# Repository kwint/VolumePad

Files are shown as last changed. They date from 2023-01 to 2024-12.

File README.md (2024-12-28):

# VolumePad

Proof of concept of a numpad / macropad with motorized faders to control volume. Fader position is also updated if you change the volume on the pc.

The main problem it tries to solve is noisy friends in discord while you are trying to clutch a csgo match

Current state of the project; PCB needs a lot of work, the original motor driver uses to much power and the fingerprint of the faders is wrong. The microcontoller code fully works, it uses MIDI for communication with the host. On windows you can use [MIDI Mixer](https://www.midi-mixer.com/). Haven't found a similar solution yet on linux, but shouldn't be hard to make. (The code in `code/host` is from before I moved the project over to MIDI).

https://user-images.githubusercontent.com/7907280/210675597-fe70f985-09b6-4afa-9840-3089a5ae9c90.mp4

## TODO:
### Code:
 - Create code for host machine
 - The capacitive button check needs work, might be electrical related
 - Clean up

### Electrical
 - Use newer motor driver
 - Fix footprint of faders
 - I think something is wrong with the capacitive button wiring

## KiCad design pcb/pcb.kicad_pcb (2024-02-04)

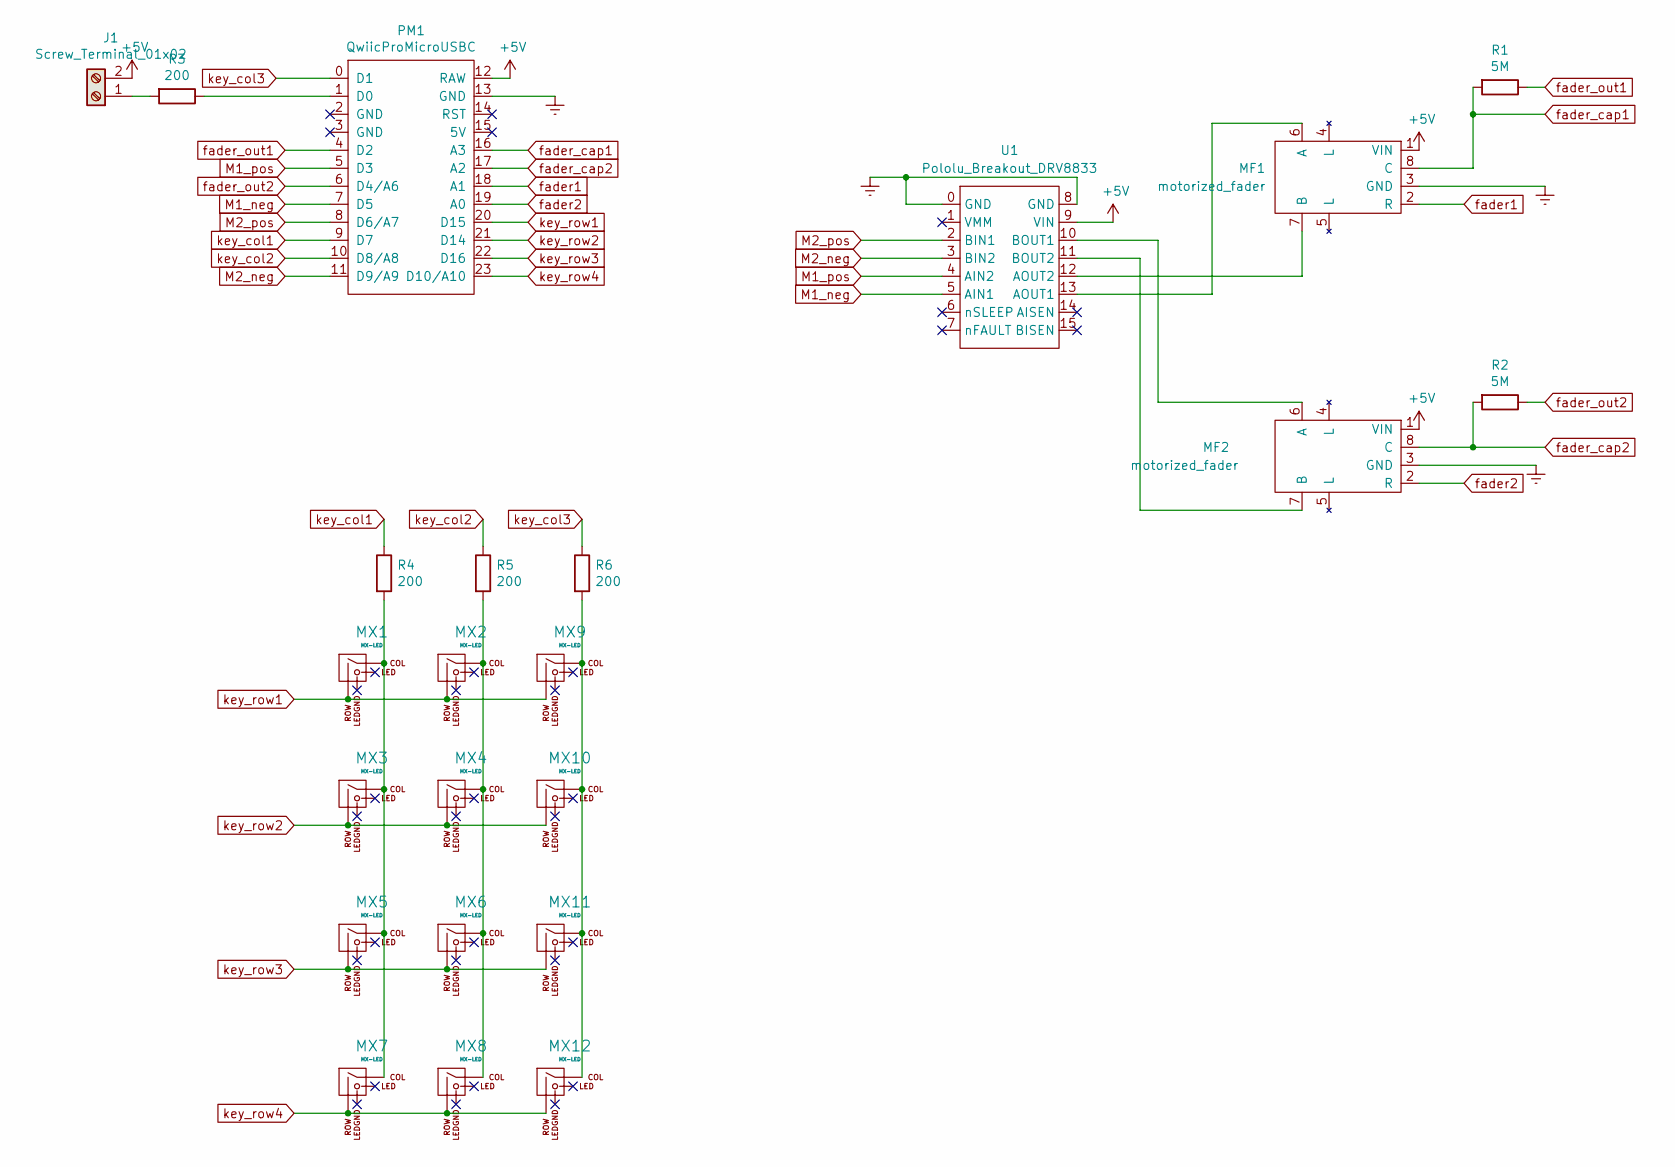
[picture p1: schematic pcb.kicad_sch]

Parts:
J1: Screw_Terminal_01x02; TerminalBlock_bornier-2_P5.08mm
MF1, MF2: motorized_fader
MX1, MX2, MX3, MX4, MX5, MX6, MX7, MX8, MX9, MX10, MX11, MX12: MX-LED; SW_Cherry_MX_1.00u_PCB
PM1: QwiicProMicroUSBC
R1, R2: 5M; R_Axial_DIN0207_L6.3mm_D2.5mm_P10.16mm_Horizontal
R3, R4, R5, R6: 200; R_Axial_DIN0207_L6.3mm_D2.5mm_P10.16mm_Horizontal
U1: Pololu_Breakout_DRV8833; Pololu_DRV8833

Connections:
+5V: J1.2, MF1.1 (VIN), MF2.1 (VIN), PM1.12 (RAW), U1.9 (VIN)
Earth: MF1.3 (GND), MF2.3 (GND), PM1.13 (GND), U1.0 (GND), U1.8 (GND)
M1_neg: PM1.7 (D5), U1.5 (AIN1)
M1_pos: PM1.5 (D3), U1.4 (AIN2)
M2_neg: PM1.11 (D9/A9), U1.3 (BIN2)
M2_pos: PM1.8 (D6/A7), U1.2 (BIN1)
unnamed: J1.1, R3.2
unnamed: MF1.6 (A), U1.13 (AOUT1)
unnamed: MF1.7 (B), U1.12 (AOUT2)
unnamed: MF2.6 (A), U1.10 (BOUT1)
unnamed: MF2.7 (B), U1.11 (BOUT2)
unnamed: MX1.1 (COL), MX3.1 (COL), MX5.1 (COL), MX7.1 (COL), R4.2
unnamed: MX2.1 (COL), MX4.1 (COL), MX6.1 (COL), MX8.1 (COL), R5.2
unnamed: MX9.1 (COL), MX10.1 (COL), MX11.1 (COL), MX12.1 (COL), R6.2
unnamed: PM1.1 (D0), R3.1
fader1: MF1.2 (R), PM1.18 (A1)
fader2: MF2.2 (R), PM1.19 (A0)
fader_cap1: MF1.8 (C), PM1.16 (A3), R1.2
fader_cap2: MF2.8 (C), PM1.17 (A2), R2.2
fader_out1: PM1.4 (D2), R1.1
fader_out2: PM1.6 (D4/A6), R2.1
key_col1: PM1.9 (D7), R4.1
key_col2: PM1.10 (D8/A8), R5.1
key_col3: PM1.0 (D1), R6.1
key_row1: MX1.2 (ROW), MX2.2 (ROW), MX9.2 (ROW), PM1.20 (D15)
key_row2: MX3.2 (ROW), MX4.2 (ROW), MX10.2 (ROW), PM1.21 (D14)
key_row3: MX5.2 (ROW), MX6.2 (ROW), MX11.2 (ROW), PM1.22 (D16)
key_row4: MX7.2 (ROW), MX8.2 (ROW), MX12.2 (ROW), PM1.23 (D10/A10)

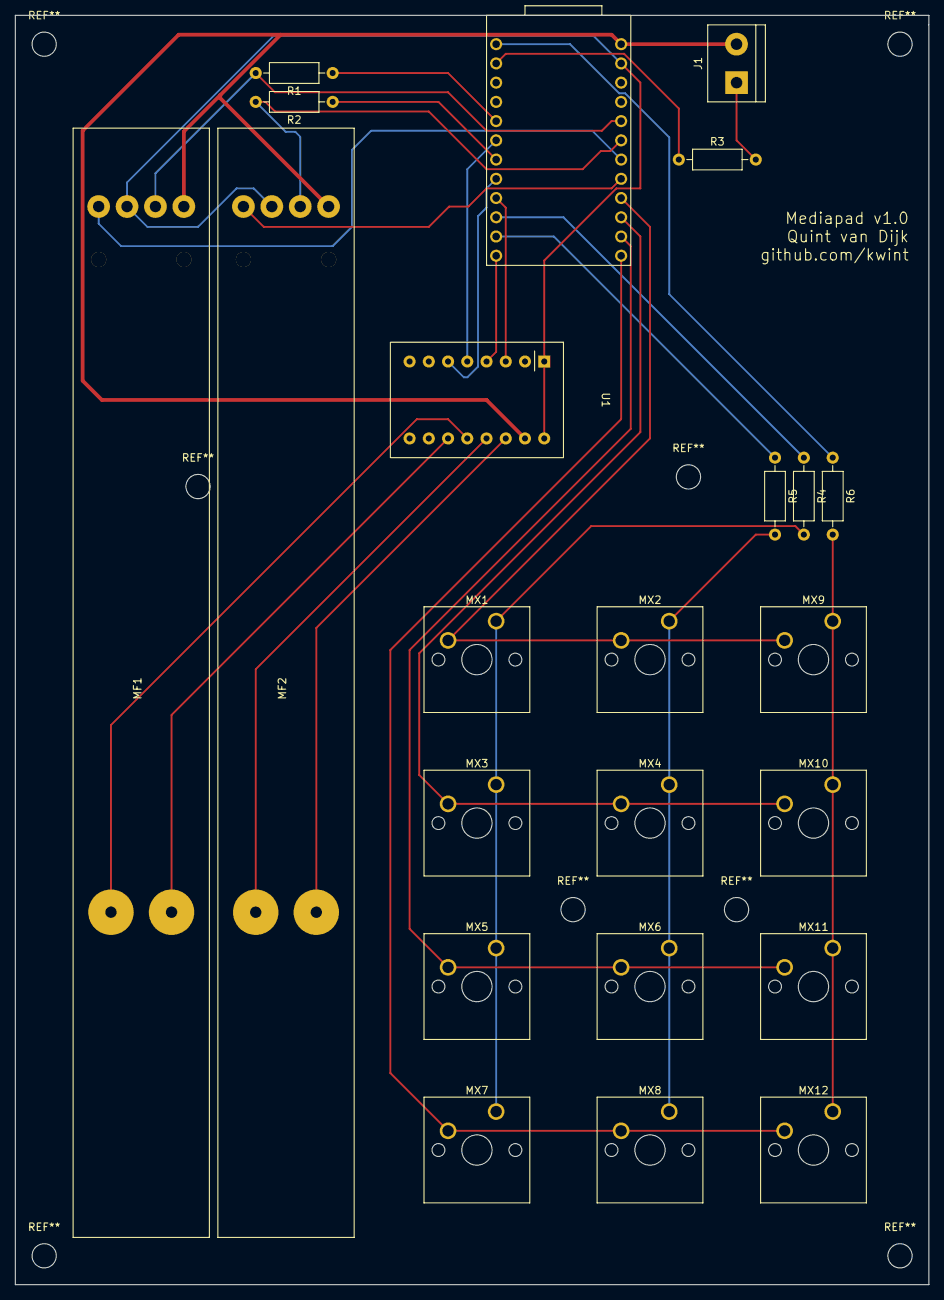
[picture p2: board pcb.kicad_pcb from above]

Board: 2 copper layers, 120.6 x 167.6 mm, 23 parts (0 on the bottom side), 28 nets.

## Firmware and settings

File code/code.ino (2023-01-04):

#include <Arduino.h>
#include "Adafruit_Keypad.h"
#include "order.h"
#include "slave.h"
#include "parameters.h"

bool isConnected = false; ///< True if the connection with the master is available

int RXLED = 17; // The RX LED has a defined Arduino pin
// Note: The TX LED was not so lucky, we'll need to use pre-defined
// macros (TXLED1, TXLED0) to control that.
// (We could use the same macros for the RX LED too -- RXLED1,
//  and RXLED0.)

int16_t fader0Pos = 0;
int16_t fader1Pos = 0;

int16_t oldFader0Pos = 0;
int16_t oldFader1Pos = 0;

bool fader0Updating = false;
bool fader1Updating = false;

unsigned long lastDebug;

Adafruit_Keypad numpad = Adafruit_Keypad(makeKeymap(keys), rowPins, colPins, ROWS, COLS);

void setup()
{
  // Init Serial
  Serial.begin(SERIAL_BAUD);

  pinMode(fader0Up, OUTPUT);
  digitalWrite(fader0Up, LOW);
  pinMode(fader0Down, OUTPUT);
  digitalWrite(fader0Down, LOW);

  pinMode(fader1Up, OUTPUT);
  digitalWrite(fader1Up, LOW);
  pinMode(fader1Down, OUTPUT);
  digitalWrite(fader1Down, LOW);

  // Wait until the arduino is isConnected to master
  while (!isConnected)
  {
    writeOrder(HELLO);
    waitForBytes(1, 1000);
    getMessageFromSerial();
  }
}

void loop()
{
  getMessageFromSerial();
  setFaders();

  sendFaders();
}

void sendFaders()
{
  int16_t fader0CurrentPos;
  int16_t fader1CurrentPos;

  fader0CurrentPos = analogRead(fader0Read);
  fader1CurrentPos = analogRead(fader1Read);

  if (!fader0Updating && (fader0CurrentPos < (oldFader0Pos - faderHysteresis) || fader0CurrentPos > (oldFader0Pos + faderHysteresis)))
  {
    writeOrder(FADER0);
    writeI16(fader0CurrentPos);
    writeI16(32767);
    oldFader0Pos = fader0CurrentPos;
  }
  if (!fader1Updating && (fader1CurrentPos < (oldFader1Pos - faderHysteresis) || fader1CurrentPos > (oldFader1Pos + faderHysteresis)))
  {
    writeOrder(FADER1);
    writeI16(fader1CurrentPos);
    writeI16(32767);
    oldFader1Pos = fader1CurrentPos;
  }
}

void setFaders()
{
  int16_t fader0CurrentPos;
  int16_t fader1CurrentPos;

  if (fader0Updating)
  {
    fader0CurrentPos = analogRead(fader0Read);
    oldFader0Pos = fader0CurrentPos;
    if (fader0CurrentPos > (fader0Pos - faderHysteresis) && fader0CurrentPos < (fader0Pos + faderHysteresis))
    {
      fader0Updating = false;
      digitalWrite(fader0Down, LOW);
      digitalWrite(fader0Up, LOW);
    }
    else if (fader0Pos < fader0CurrentPos)
    {
      digitalWrite(fader0Up, LOW);
      analogWrite(fader0Down, motorSpeed);
    }
    else if (fader0Pos > fader0CurrentPos)
    {
      digitalWrite(fader0Down, LOW);
      analogWrite(fader0Up, motorSpeed);
    }
  }

  if (fader1Updating)
  {
    fader1CurrentPos = analogRead(fader1Read);
    oldFader1Pos = fader1CurrentPos;
    if (fader1CurrentPos > (fader1Pos - faderHysteresis) && analogRead(fader1Read) < (fader1Pos + faderHysteresis))
    {
      fader1Updating = false;
      digitalWrite(fader1Down, LOW);
      digitalWrite(fader1Up, LOW);
    }
    else if (fader1Pos < fader1CurrentPos)
    {
      digitalWrite(fader1Up, LOW);
      analogWrite(fader1Down, motorSpeed);
    }
    else if (fader1Pos > fader1CurrentPos)
    {
      digitalWrite(fader1Down, LOW);
      analogWrite(fader1Up, motorSpeed);
    }
  }
}

void getMessageFromSerial()
{
  if (Serial.available() > 0)
  {
    // The first byte received is the instruction
    Order orderReceived = readOrder();

    if (orderReceived == HELLO)
    {
      // If the cards haven't say hello, check the connection
      if (!isConnected)
      {
        isConnected = true;
        writeOrder(HELLO);
      }
      else
      {
        // If we are already isConnected do not send "hello" to avoid infinite loop
        writeOrder(ALREADY_CONNECTED);
      }
    }
    else if (orderReceived == ALREADY_CONNECTED)
    {
      isConnected = true;
    }
    else
    {
      switch (orderReceived)
      {
      case FADER0:
      {
        fader0Pos = readI16();
        fader0Updating = true;
        break;
      }
      case FADER1:
      {
        fader1Pos = readI16();
        fader1Updating = true;
        break;
      }
      // Unknown order
      default:
        writeOrder(ERROR);
        writeI16(404);
        return;
      }
    }
  }
}

Order readOrder()
{
  return (Order)Serial.read();
}

void waitForBytes(int num_bytes, unsigned long timeout)
{
  unsigned long startTime = millis();
  // Wait for incoming bytes or exit if timeout
  while ((Serial.available() < num_bytes) && (millis() - startTime < timeout))
  {
  }
}

// NOTE : Serial.readBytes is SLOW
// this one is much faster, but has no timeout
void readSignedBytes(int8_t *buffer, size_t n)
{
  size_t i = 0;
  int c;
  while (i < n)
  {
    c = Serial.read();
    if (c < 0)
      break;
    *buffer++ = (int8_t)c; // buffer[i] = (int8_t)c;
    i++;
  }
}

int8_t readI8()
{
  waitForBytes(1, 100); // Wait for 1 byte with a timeout of 100 ms
  return (int8_t)Serial.read();
}

int16_t readI16()
{
  int8_t buffer[2];
  waitForBytes(2, 100); // Wait for 2 bytes with a timeout of 100 ms
  readSignedBytes(buffer, 2);
  return (((int16_t)buffer[0]) & 0xff) | (((int16_t)buffer[1]) << 8 & 0xff00);
}

int32_t readI32()
{
  int8_t buffer[4];
  waitForBytes(4, 200); // Wait for 4 bytes with a timeout of 200 ms
  readSignedBytes(buffer, 4);
  return (((int32_t)buffer[0]) & 0xff) | (((int32_t)buffer[1]) << 8 & 0xff00) | (((int32_t)buffer[2]) << 16 & 0xff0000) | (((int32_t)buffer[3]) << 24 & 0xff000000);
}

void writeOrder(enum Order myOrder)
{
  uint8_t *Order = (uint8_t *)&myOrder;
  Serial.write(Order, sizeof(uint8_t));
}

void writeI8(int8_t num)
{
  Serial.write(num);
}

void writeI16(int16_t num)
{
  int8_t buffer[2] = {(int8_t)(num & 0xff), (int8_t)(num >> 8)};
  Serial.write((uint8_t *)&buffer, 2 * sizeof(int8_t));
}

void writeI32(int32_t num)
{
  int8_t buffer[4] = {(int8_t)(num & 0xff), (int8_t)(num >> 8 & 0xff), (int8_t)(num >> 16 & 0xff), (int8_t)(num >> 24 & 0xff)};
  Serial.write((uint8_t *)&buffer, 4 * sizeof(int8_t));
}

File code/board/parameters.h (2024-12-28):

#ifndef PARAMETERS_H
#define PARAMETERS_H

#define SERIAL_BAUD 115200 // Baudrate

const int fader0Up = 3;
const int fader0Down = 5;
const int fader0Read = A1;
const int fader0Cap = A3;

const int fader1Up = 6;
const int fader1Down = 9;
const int fader1Read = A0;
const int fader1Cap = A2;

const int faderHysteresis = 15;

const int waitTime = 100;
const int outputs[] = {fader0Up, fader0Down, fader1Up, fader1Down, fader0Cap, fader1Cap};

const int motorSpeed = 210;

const byte ROWS = 4; // rows
const byte COLS = 3; // columns
// define the symbols on the buttons of the keypads
char keys[ROWS][COLS] = {
    {'0', '1', '2'},
    {'3', '4', '5'},
    {'6', '7', '8'},
    {'9', 'A', 'B'}};
byte rowPins[ROWS] = {15, 14, 16, 10};
byte colPins[COLS] = {7, 8, 1};

// If DEBUG is set to true, the arduino will send back all the received messages
#define DEBUG false

#endif

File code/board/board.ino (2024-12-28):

#include <Arduino.h>
#include "Adafruit_Keypad.h"
#include "parameters.h"
#include "usbmidi.h"

bool isConnected = false; ///< True if the connection with the master is available
const int channel = 1;

int RXLED = 17; // The RX LED has a defined Arduino pin
// Note: The TX LED was not so lucky, we'll need to use pre-defined
// macros (TXLED1, TXLED0) to control that.
// (We could use the same macros for the RX LED too -- RXLED1,
//  and RXLED0.)

unsigned long lastDebug;

#define MIDI_NOTE_OFF   0b10000000
#define MIDI_NOTE_ON    0b10010000
#define MIDI_CONTROL    0b10110000
#define MIDI_PITCH_BEND 0b11100000

typedef struct
{
  int index;
  int16_t pos;
  int16_t prevPos;
  bool updating;
  int upPin;
  int downPin;
  int readPin;
  int capPin;
  int16_t capBaseLine;

} FADER;

FADER faders[2] = {{0, 0, 0, false, fader0Up, fader0Down, fader0Read, fader0Cap, 0}, {1, 0, 0, false, fader1Up, fader1Down, fader1Read, fader1Cap, 0}};
const int faderCount = 2;
Adafruit_Keypad numpad = Adafruit_Keypad(makeKeymap(keys), rowPins, colPins, ROWS, COLS);

void setup()
{

  for (int i = 0; i < faderCount; i++)
  {
    pinMode(faders[i].upPin, OUTPUT);
    digitalWrite(faders[i].upPin, LOW);
    pinMode(faders[i].downPin, OUTPUT);
    digitalWrite(faders[i].downPin, LOW);

    pinMode(faders[i].readPin, INPUT);

  }
  numpad.begin();
  Serial.begin(9600);


}

void loop()
{
  USBMIDI.poll();

  while (USBMIDI.available()) {
      //Parse MIDI
      u8 command=0, channel=0, key=0, control=0, value=0, velocity=0;

      //Skip to beginning of next message (silently dropping stray data bytes)
      while(!(USBMIDI.peek() & 0b10000000)) USBMIDI.read();

      command = USBMIDI.read();
      channel = (command & 0b00001111)+1;
      command = command & 0b11110000;

      switch(command) {
        case MIDI_NOTE_ON:
        case MIDI_NOTE_OFF:
          if(USBMIDI.peek() & 0b10000000) continue; key      = USBMIDI.read();
          if(USBMIDI.peek() & 0b10000000) continue; velocity = USBMIDI.read();
          break;
        case MIDI_CONTROL:
          if(USBMIDI.peek() & 0b10000000) continue; control = USBMIDI.read();
          if(USBMIDI.peek() & 0b10000000) continue; value = USBMIDI.read();

          if (!capTouched(faders[control-20].capPin, 4250)){
            faders[control - 20].pos = map(value, 0, 127, 0, 1023);
            faders[control - 20].updating = true;
          }
          break;

      }

  }
  setFaders();

  sendFaders();
  sendButtons();
  
	USBMIDI.flush();
}

void sendButtons()
{
  numpad.tick();
  while (numpad.available())
  {
    keypadEvent e = numpad.read();
    if (e.bit.EVENT == KEY_JUST_PRESSED)
    {
      sendNote(channel, e.bit.KEY, 127);
    }
    else if (e.bit.EVENT == KEY_JUST_RELEASED)
    {
      sendNote(channel, e.bit.KEY, 0);
    }
  }
}

void sendFaders()
{
  int16_t faderCurrentPos;

  for (int i = 0; i < faderCount; i++)
  {
    faderCurrentPos = analogRead(faders[i].readPin);
    if (!faders[i].updating && (faderCurrentPos < (faders[i].prevPos - faderHysteresis) || faderCurrentPos > (faders[i].prevPos + faderHysteresis)))
    {
      sendCC(channel, i + 40, map(faderCurrentPos, 0, 1023, 0, 127));
      faders[i].prevPos = faderCurrentPos;
    }
  }
}

void sendCC(uint8_t channel, uint8_t control, uint8_t value)
{
  USBMIDI.write(0xB0 | (channel & 0xf));
  USBMIDI.write(control & 0x7f);
  USBMIDI.write(value & 0x7f);
}

void sendNote(uint8_t channel, uint8_t note, uint8_t velocity)
{
  USBMIDI.write((velocity != 0 ? 0x90 : 0x80) | (channel & 0xf));
  USBMIDI.write(note & 0x7f);
  USBMIDI.write(velocity & 0x7f);
}

void setFaders()
{
  int16_t faderCurrentPos;

  for (int i = 0; i < faderCount; i++)
  {
    if (faders[i].updating)
    {
      faderCurrentPos = analogRead(faders[i].readPin);
      faders[i].prevPos = faderCurrentPos;
      if (faderCurrentPos > (faders[i].pos - faderHysteresis) && faderCurrentPos < (faders[i].pos + faderHysteresis))
      {
        faders[i].updating = false;
        digitalWrite(faders[i].upPin, LOW);
        digitalWrite(faders[i].downPin, LOW);
      }
      else if (faders[i].pos < faderCurrentPos)
      {
        digitalWrite(faders[i].upPin, LOW);
        analogWrite(faders[i].downPin, motorSpeed);
      }
      else if (faders[i].pos > faderCurrentPos)
      {
        digitalWrite(faders[i].downPin, LOW);
        analogWrite(faders[i].upPin, motorSpeed);
      }
    }
  }
}

bool capTouched(int pin, int baseline){
    pinMode(pin, OUTPUT);
    digitalWrite(pin, HIGH);
    pinMode(pin,INPUT);
    int count = 0;
    unsigned long start_time = millis();
    while (millis() - start_time < 25) { // Check for 50 ms
        if (digitalRead(pin)) {
            count++;
        }
    }
    Serial.println(count);
    return count < baseline;
}

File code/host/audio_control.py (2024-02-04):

from typing import TypeAlias

import pulsectl
import pulsectl_asyncio

import constants as cont

Pulse: TypeAlias = pulsectl_asyncio.PulseAsync
PulseEvent: TypeAlias = pulsectl.PulseEventInfo
SinkInInfo: TypeAlias = pulsectl.PulseSinkInputInfo


async def init():
    pulse = pulsectl_asyncio.PulseAsync("volumepad")
    await pulse.connect()

    return pulse
    

async def get_sinks(pulse: Pulse, channel, single=False):
    sinks = []
    in_sinks = await pulse.sink_input_list()
    for in_sink in in_sinks:
        if in_sink.proplist.get("application.name") in cont.CHANNELS[channel]:
            sinks.append(in_sink)
            if single:
                break

    if len(sinks) == 0:
        return None

    return sinks


async def change_volume(pulse: pulsectl_asyncio.PulseAsync, channel, volume: int):
    sinks = await get_sinks(pulse, channel, False)

    if sinks is None:
        return None

    for sink in sinks:
        await pulse.volume_set_all_chans(sink, volume / 1024)


async def get_volume(pulse: pulsectl_asyncio.PulseAsync, channel: int):
    sinks = await get_sinks(pulse, channel, True)

    if sinks is None:
        return None

    volume = await pulse.volume_get_all_chans(sinks[0])

    return int(volume * 1024)

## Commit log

2023-01-04 init commit
    [pcb-B_Cu.gbr, pcb-B_Mask.gbr, pcb-B_SilkS.gbr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]
2023-01-05 Arduino code cleanup
2023-03-12 WIP async and new pcb layout
    [pcb.kicad_pcb, pcb.kicad_sch]
